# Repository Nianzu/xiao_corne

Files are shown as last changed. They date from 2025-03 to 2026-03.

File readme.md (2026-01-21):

https://docs.espressif.com/projects/rust/book/getting-started/toolchain.html
# Toolchain
```
sudo apt install build-essential
cargo install espup --locked 
espup install
cat $HOME/export-esp.sh >> ~/.bashrc
```
# Tooling
```
cargo install esp-generate --locked
cargo install espflash --locked
cargo install esp-config --features=tui --locked
```

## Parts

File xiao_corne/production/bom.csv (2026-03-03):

Designator | Footprint | Quantity | Value | LCSC Part #
BT1 | PinHeader_1x02_P2.00mm_Vertical | 1 | Battery
C1, C2 | 0805 | 2 | 10uF
C14, C15, C16 | 0805 | 3 | 4.7u
C3 | 0805 | 1 | 1u
C4 | 0805 | 1 | 22u
C7 | 0805 | 1 | 0.1u
C8, C9 | 0805 | 2 | 100nF
D1, D2 | TVS_ESD321DPYR | 2 | ESD321DPYR
D16, D17, D18, D19, D20, D21, D22, D23, D47, D48, D49, D50, D51, D52, D53, D54, D73, D74, D75, D76, D77 | LED_SK6812MINI | 21 | LED_SK6812MINI | C5149201
J1 | GCT_USB4110GFA | 1 | USB4110GFA
J6 | PinHeader_1x04_P2.54mm_Vertical | 1 | Conn_01x04_Socket
R1, R3 | 0805 | 2 | 100k
R10, R7, R8, R9 | 0805 | 4 | 10k
R2, R4 | 0805 | 2 | 22
R5, R6 | 0805 | 2 | 5.1k
S1 | SW_SLW-864574-5A-RA-N-D | 1 | SLW-864574-5A-RA-N-D
SW1, SW11, SW12, SW13, SW14, SW15, SW2, SW21, SW22, SW23, SW24, SW25, SW3, SW31, SW32, SW33, SW34, SW35, SW4, SW41, SW5 | Hotswap_Choc_V1V2 | 21 | SW_Push
SW6 | MJTP1117 | 1 | SW_Push
U1 | D14 | 1 | SN74AHCT125DR
U2 | ESP32-S3-WROOM-1 | 1 | ESP32-S3-WROOM-1
U4 | RGT0016C | 1 | BQ24232RGTR
U5 | QFN-12_MPM3810_MNP | 1 | MPM3810GQB-33-Z

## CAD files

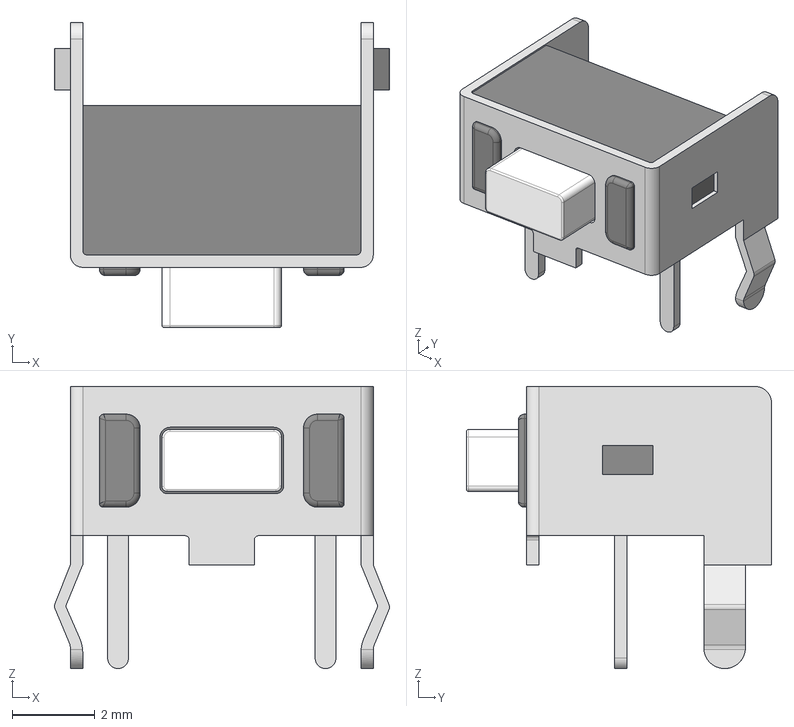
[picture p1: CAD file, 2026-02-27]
xiao_corne/MJTP1117-5483_ASM.step
8.07 x 7.35 x 6.80 mm
MJTP1117-5506_2
MJTP1117-5506_1
MJTP1117-5506_3

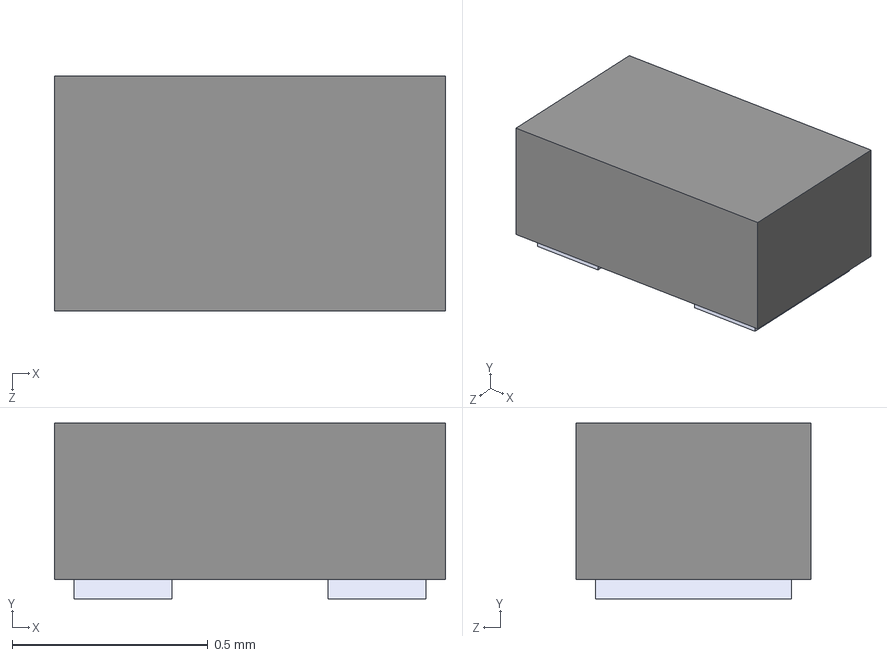
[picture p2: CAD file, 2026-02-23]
xiao_corne/ESD321DPYR/ESD321DPYR.step
1.00 x 0.45 x 0.6 mm

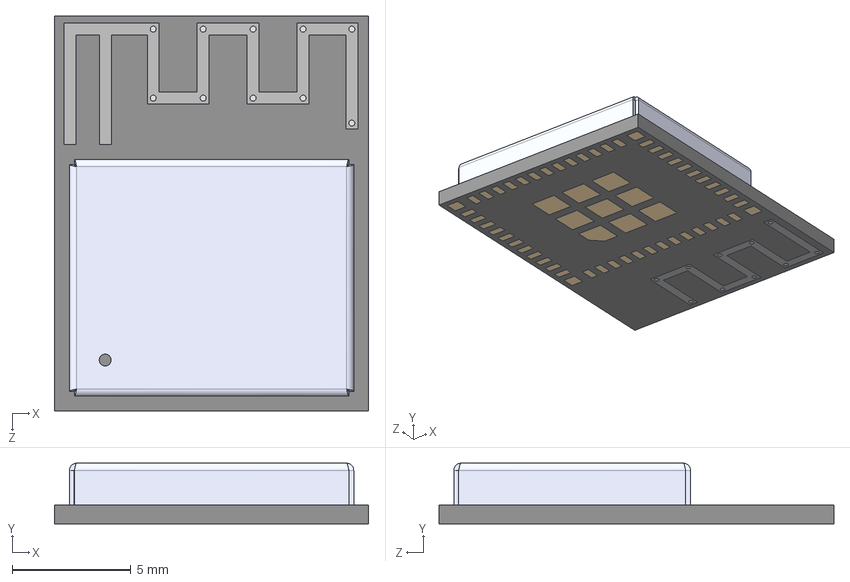
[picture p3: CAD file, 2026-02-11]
xiao_corne/ESP32_C3_MINI_1_N4/ESP32-C3-MINI-1-N4.step
13.2 x 2.55 x 16.6 mm

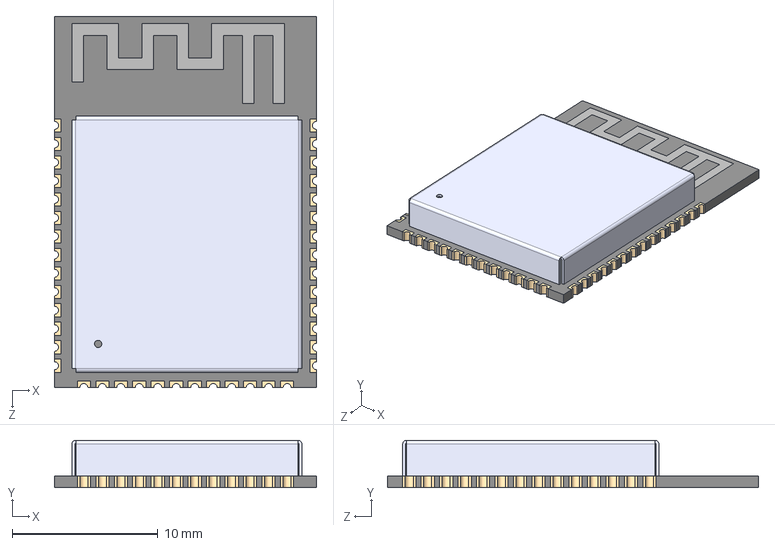
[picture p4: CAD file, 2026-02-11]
xiao_corne/ESP32_S3_WROOM_1_N4/ESP32-S3-WROOM-1-N4.step
18.0 x 3.25 x 25.5 mm

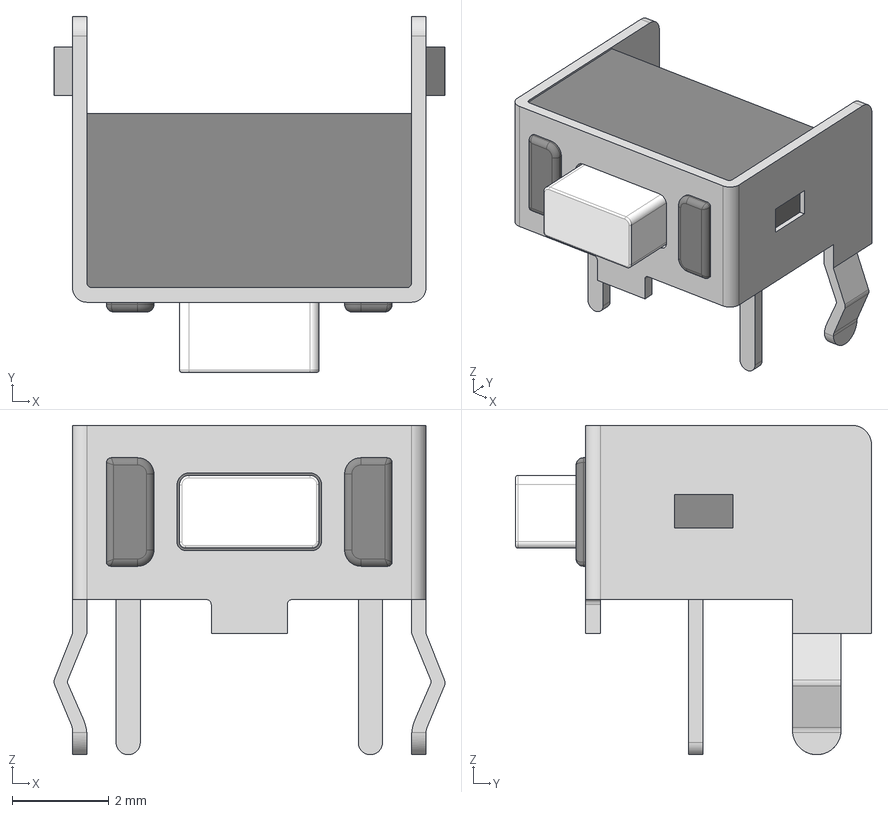
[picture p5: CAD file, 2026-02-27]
xiao_corne/LIB_MJTP1117/MJTP1117/3D/MJTP1117.stp
8.07 x 7.35 x 6.80 mm

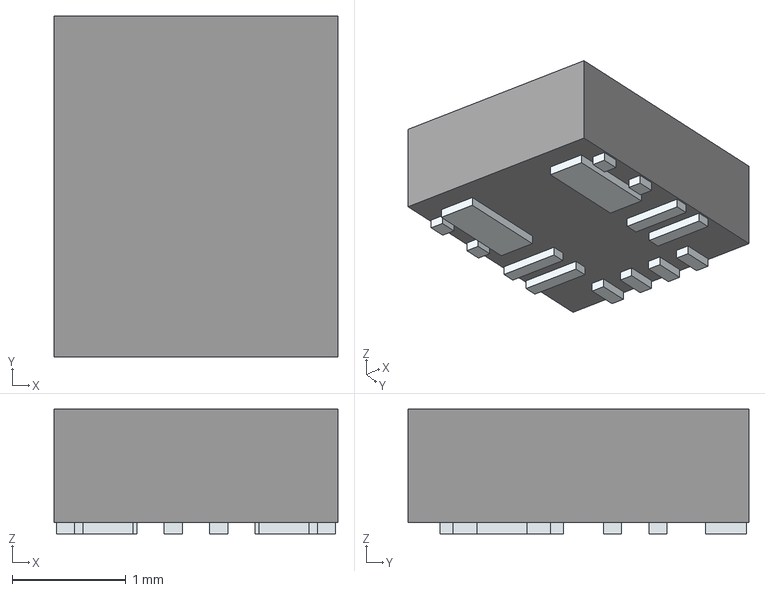
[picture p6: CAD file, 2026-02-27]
xiao_corne/LIB_MPM3810GQB-33-Z/MPM3810GQB-33-Z/3D/MPM3810GQB-33-Z.stp
2.50 x 3.00 x 1.10 mm
Pins

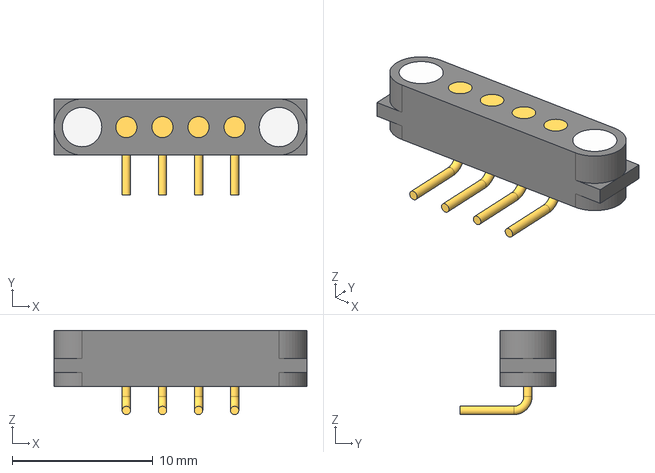
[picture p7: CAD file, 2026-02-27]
xiao_corne/Part Studio 1.step
18.0 x 6.83 x 6.00 mm

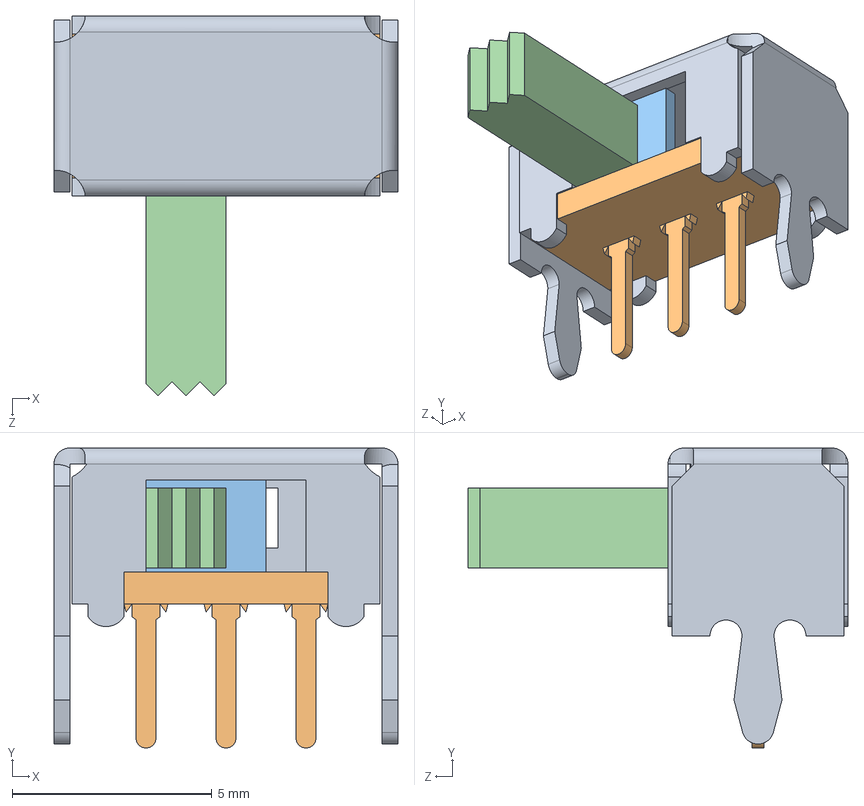
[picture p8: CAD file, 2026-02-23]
xiao_corne/SLW_864574_5A_RA_N_D/SLW-864574-5A-RA-N-D.step
8.60 x 7.50 x 9.50 mm

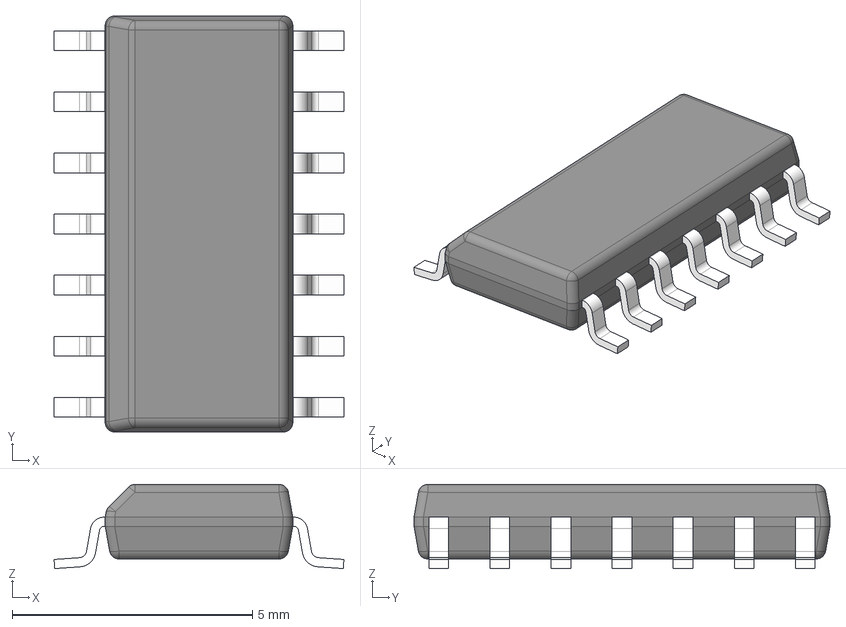
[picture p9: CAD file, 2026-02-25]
xiao_corne/SN74AHCT125DR/SN74AHCT125DR.stp
6.03 x 8.65 x 1.75 mm
BODY-SO
LEAD-SO x 14
PIN1-ID

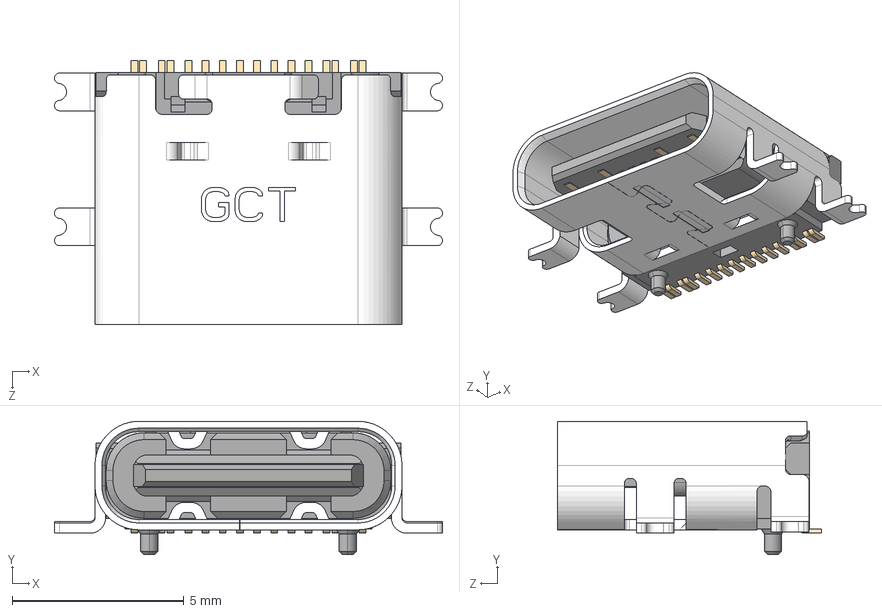
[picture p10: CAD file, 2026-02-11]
xiao_corne/USB4110_GF_A/USB4110GFA.step
11.3 x 3.89 x 7.70 mm

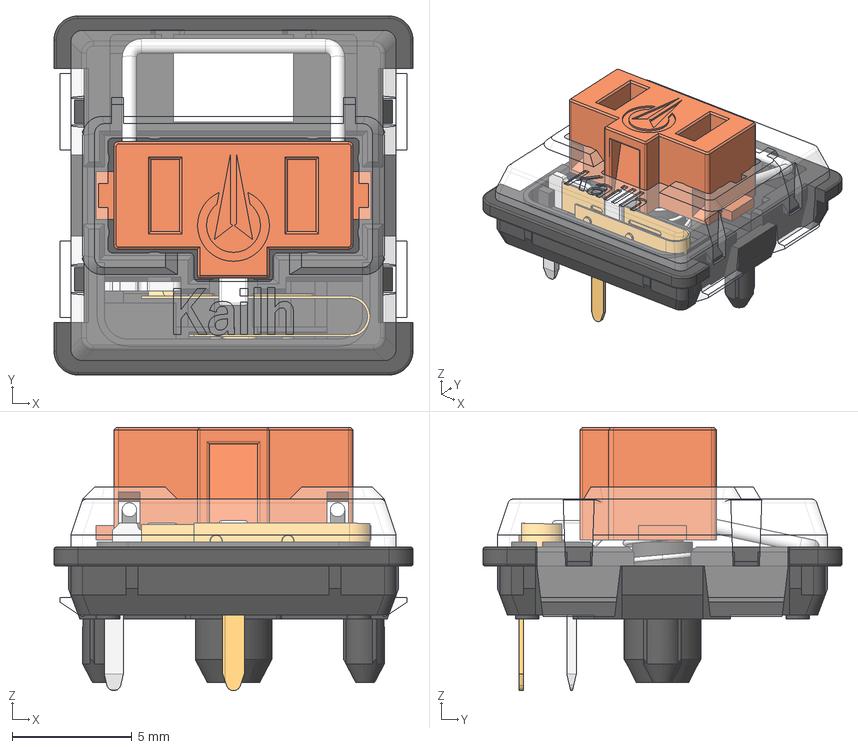
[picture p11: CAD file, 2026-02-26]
xiao_corne/red(1).step
15.0 x 15.0 x 11.0 mm
bottom_stabilizer
contact
pin1
pin2
top_stabilizer
stabilizer
stem_stabilizer
shrunken_spring

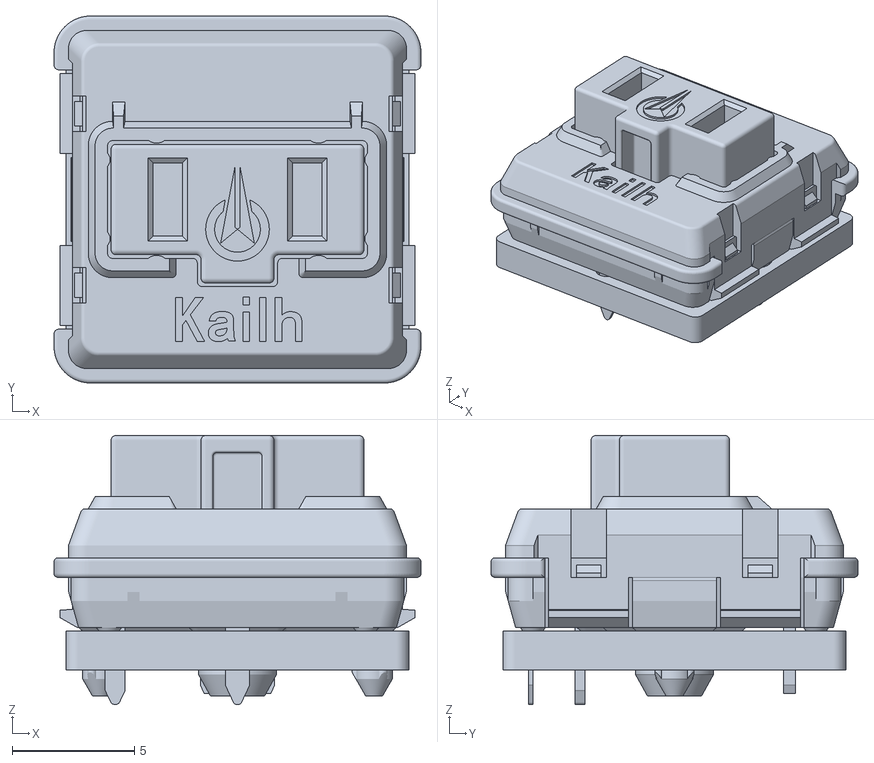
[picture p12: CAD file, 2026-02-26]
xiao_corne/Kailh Choc Low Profile Switch.stl
15.0 x 15.0 x 11.0

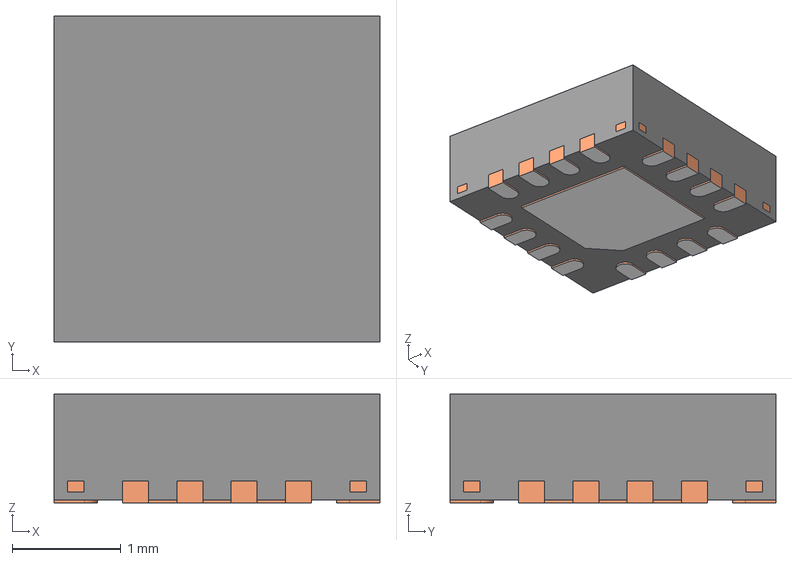
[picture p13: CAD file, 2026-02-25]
xiao_corne/BQ24232RGTR/BQ24232RGTR.stp
3.00 x 3.00 x 1.00 mm
BODY-QFN
FRAME-RGT0016C
PIN1-ID

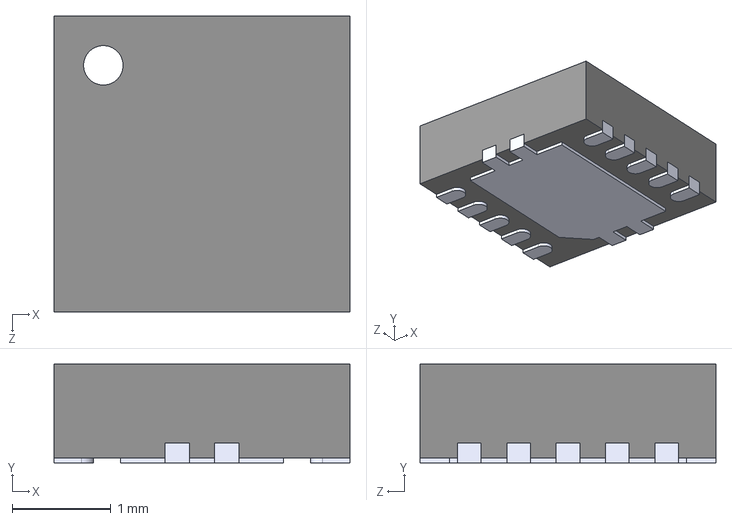
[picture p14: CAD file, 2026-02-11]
xiao_corne/TPS61201DRCT/TPS61201DRCT.step
3.00 x 1.00 x 3.00 mm

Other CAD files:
xiao_corne/LIB_MJTP1117/MJTP1117/Allegro/mjtp1117.psm
xiao_corne/LIB_MJTP1117/MJTP1117/DEHDL/mjtp1117/chips/chips.prt
xiao_corne/LIB_MPM3810GQB-33-Z/MPM3810GQB-33-Z/Allegro/mpm3810gqb33z.psm
xiao_corne/LIB_MPM3810GQB-33-Z/MPM3810GQB-33-Z/DEHDL/mpm3810gqb_33_z/chips/chips.prt

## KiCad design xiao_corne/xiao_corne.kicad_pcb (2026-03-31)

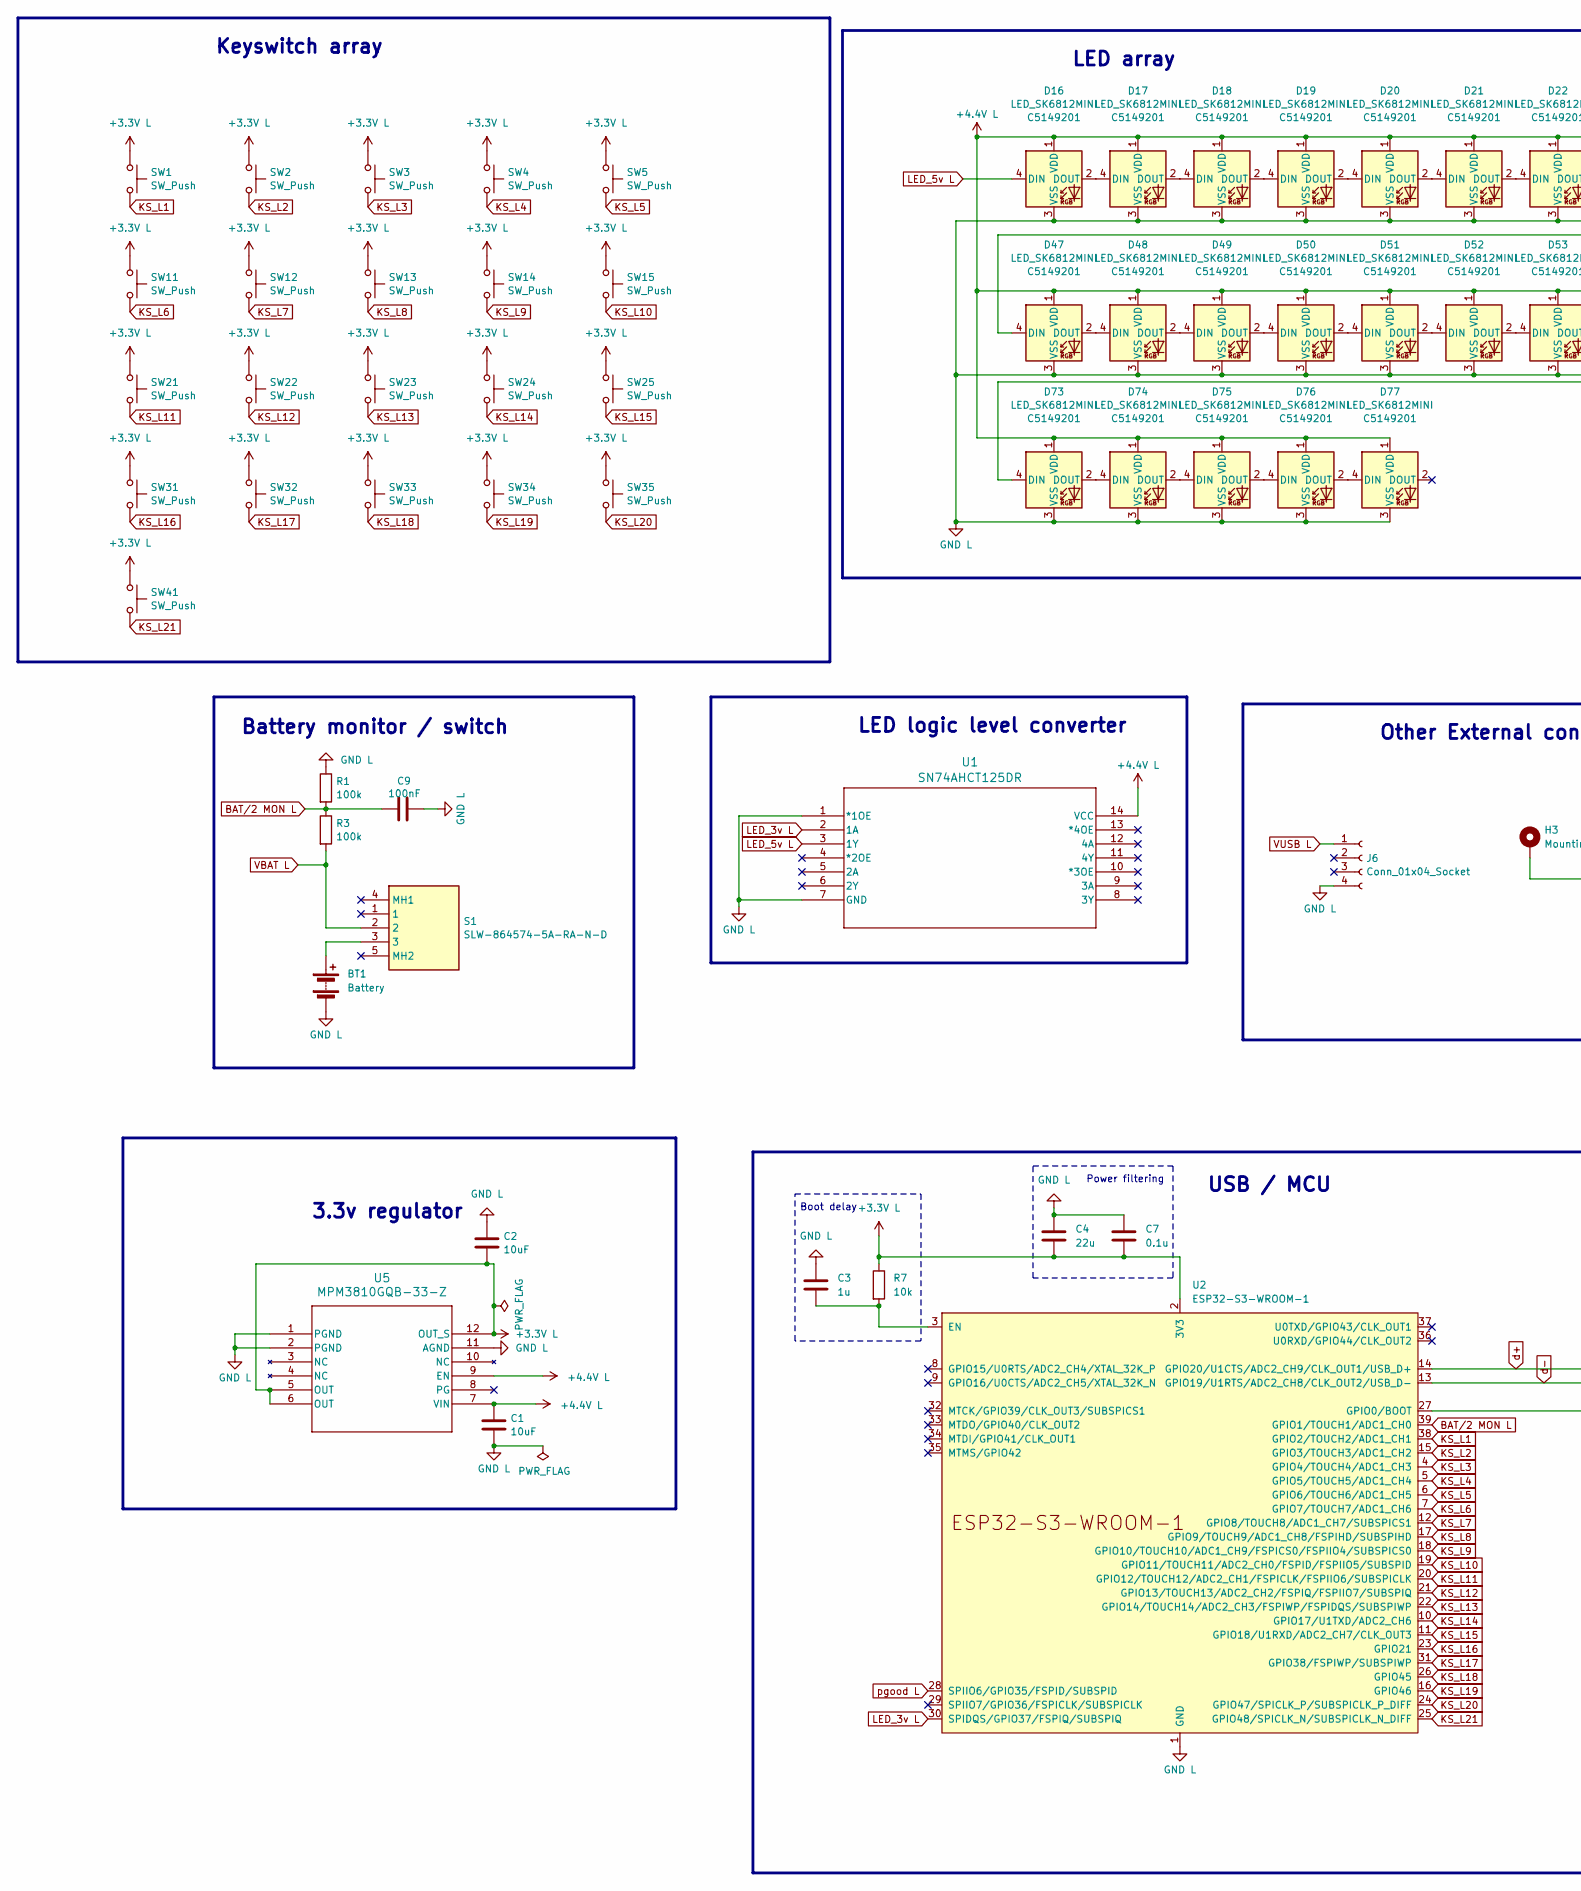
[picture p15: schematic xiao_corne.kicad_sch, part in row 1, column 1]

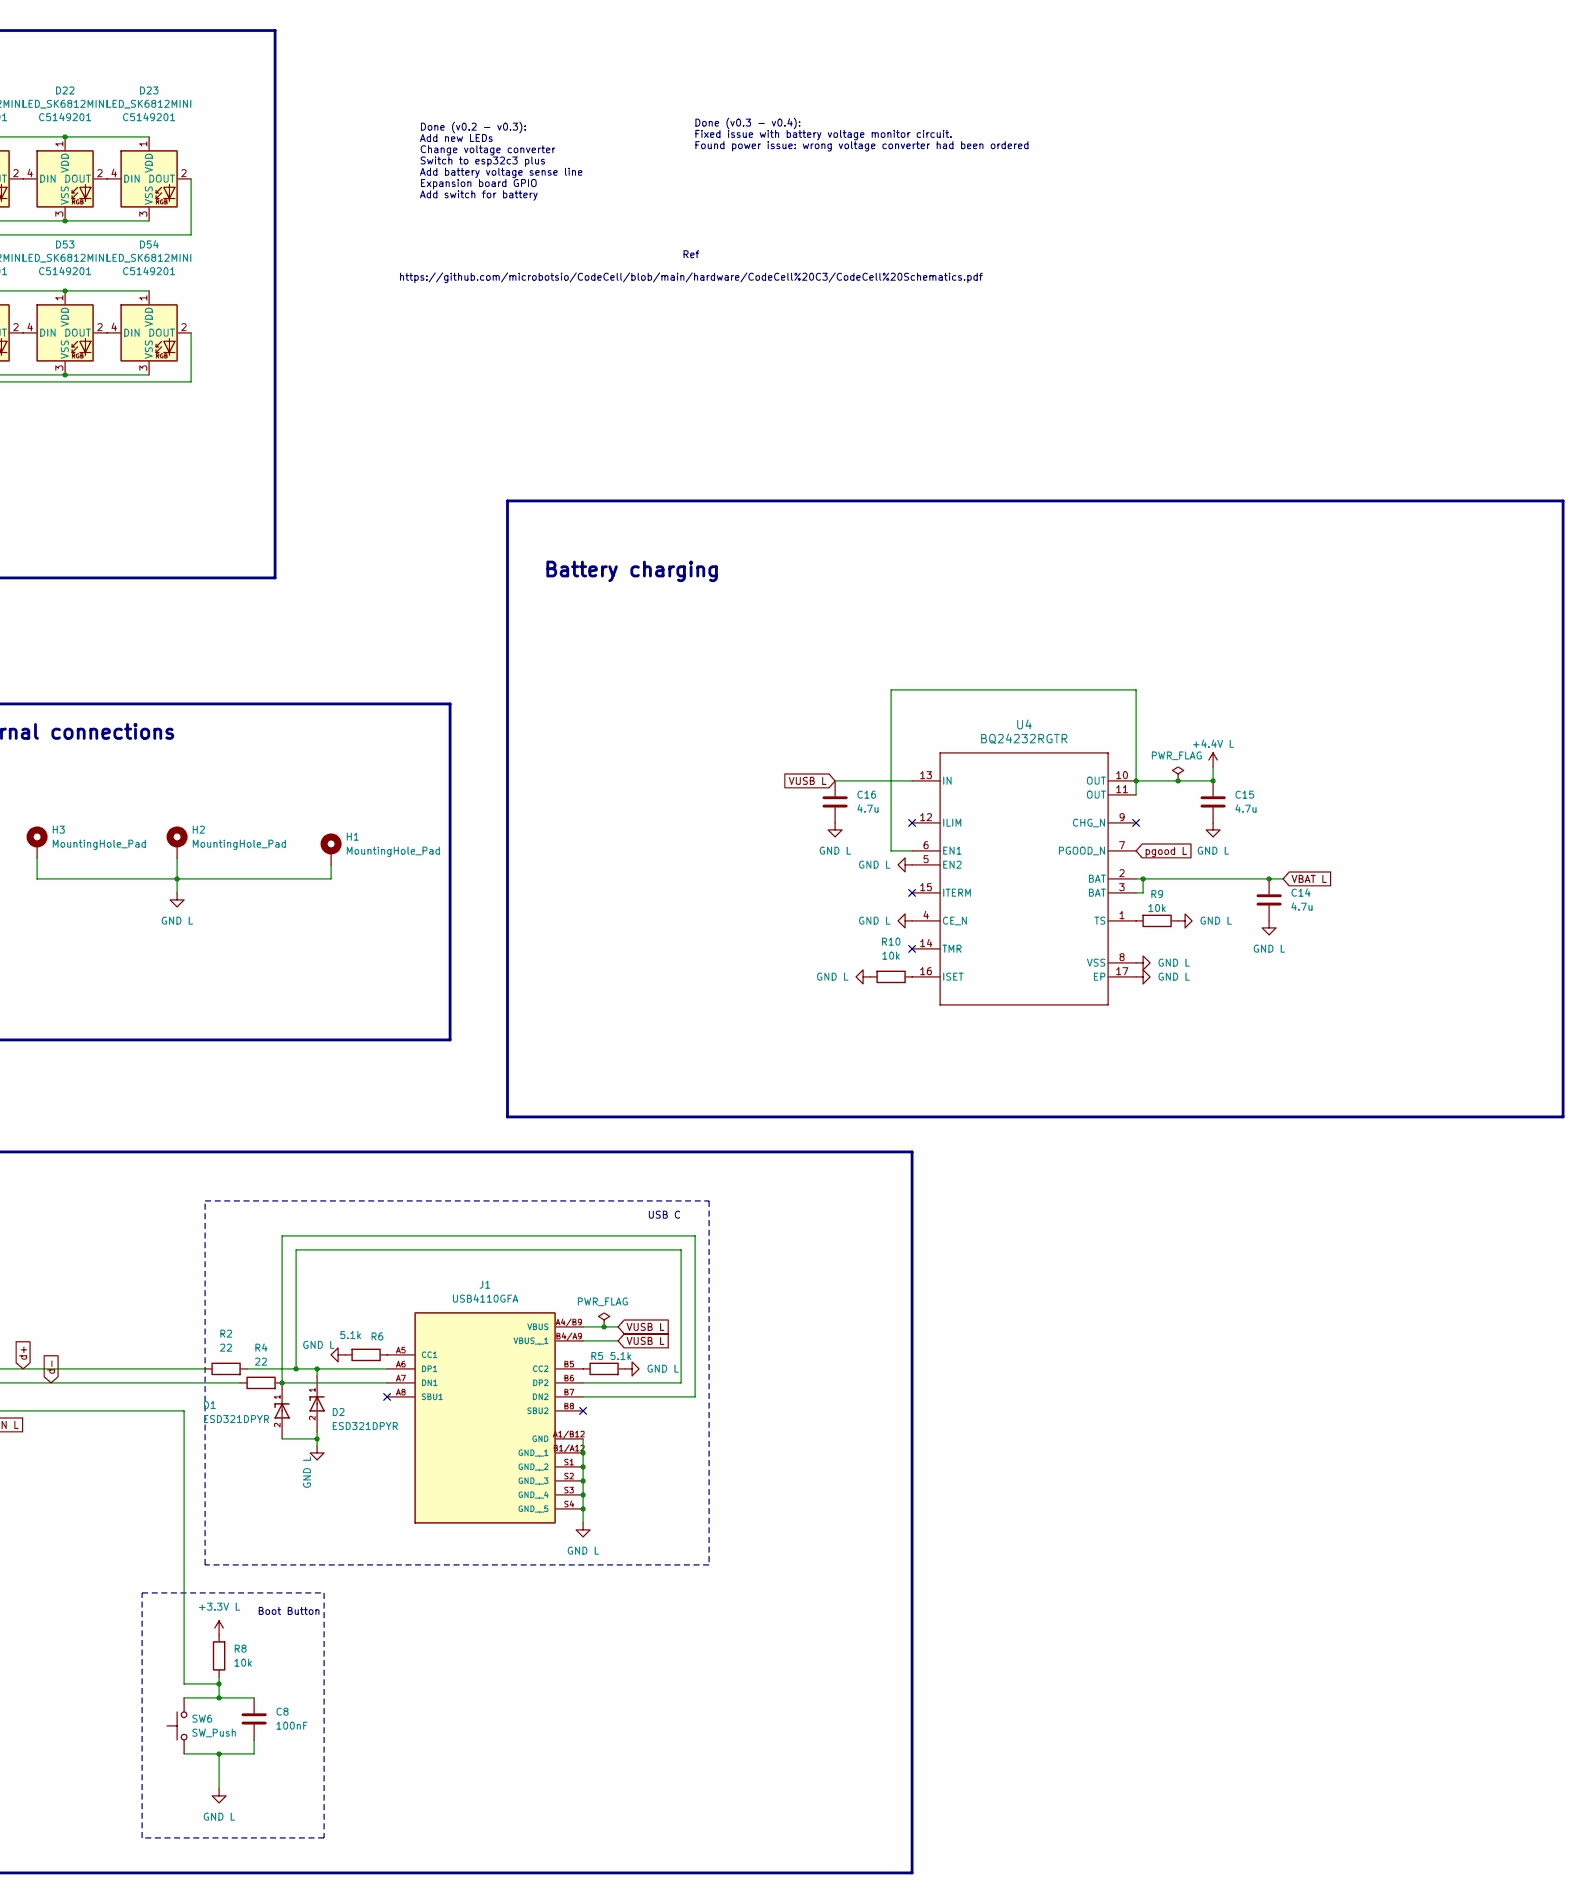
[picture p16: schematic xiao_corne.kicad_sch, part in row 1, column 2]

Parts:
BT1: Battery; PinHeader_1x02_P2.00mm_Vertical
C1, C2: 10uF; C_0805_2012Metric
C3: 1u; C_0805_2012Metric
C4: 22u; C_0805_2012Metric
C7: 0.1u; C_0805_2012Metric
C8, C9: 100nF; C_0805_2012Metric
C14, C15, C16: 4.7u; C_0805_2012Metric
D1, D2: ESD321DPYR; TVS_ESD321DPYR; PARTREV B
D16, D17, D18, D19, D20, D21, D22, D23, D47, D48, D49, D50, D51, D52, D53, D54, D73, D74, D75, D76, D77: LED_SK6812MINI; LCSC C5149201
H1, H2, H3: MountingHole_Pad; MountingHole_2.2mm_M2_ISO14580_Pad_TopBottom
J1: USB4110GFA; GCT_USB4110GFA
J6: Conn_01x04_Socket; PinHeader_1x04_P2.54mm_Vertical
R1, R3: 100k; R_0805_2012Metric
R2, R4: 22; R_0805_2012Metric
R5, R6: 5.1k; R_0805_2012Metric
R7, R8, R9, R10: 10k; R_0805_2012Metric
S1: SLW-864574-5A-RA-N-D; SW_SLW-864574-5A-RA-N-D; Mouser Part Number 179-SLW8645745ARAND
SW1, SW2, SW3, SW4, SW5, SW11, SW12, SW13, SW14, SW15, SW21, SW22, SW23, SW24, SW25, SW31, SW32, SW33, SW34, SW35, SW41: SW_Push; Hotswap_Choc_V1V2
SW6: SW_Push; MJTP1117
U1: SN74AHCT125DR; D14
U2: ESP32-S3-WROOM-1
U4: BQ24232RGTR; RGT0016C
U5: MPM3810GQB-33-Z; QFN-12_MPM3810_MNP

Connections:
+3.3V L: C2.1, C4.2, C7.2, R7.1, R8.2, SW1.1, SW2.1, SW3.1, SW4.1, SW5.1, SW11.1, SW12.1, SW13.1, SW14.1, SW15.1, SW21.1, SW22.1, SW23.1, SW24.1, SW25.1, SW31.1, SW32.1, SW33.1, SW34.1, SW35.1, SW41.1, U2.2 (3V3), U5.5 (OUT), U5.6 (OUT), U5.12 (OUT_S)
+4.4V L: C1.2, C15.1, D16.1 (VDD), D17.1 (VDD), D18.1 (VDD), D19.1 (VDD), D20.1 (VDD), D21.1 (VDD), D22.1 (VDD), D23.1 (VDD), D47.1 (VDD), D48.1 (VDD), D49.1 (VDD), D50.1 (VDD), D51.1 (VDD), D52.1 (VDD), D53.1 (VDD), D54.1 (VDD), D73.1 (VDD), D74.1 (VDD), D75.1 (VDD), D76.1 (VDD), D77.1 (VDD), U1.14 (VCC), U4.6 (EN1), U4.10 (OUT), U4.11 (OUT), U5.7 (VIN), U5.9 (EN)
BAT/2 MON L: C9.2, R1.2, R3.1, U2.39 (GPIO1/TOUCH1/ADC1_CH0)
GND L: BT1.2 (-), C1.1, C2.2, C3.1, C4.1, C7.1, C8.2, C9.1, C14.2, C15.2, C16.2, D1.2, D2.2, D16.3 (VSS), D17.3 (VSS), D18.3 (VSS), D19.3 (VSS), D20.3 (VSS), D21.3 (VSS), D22.3 (VSS), D23.3 (VSS), D47.3 (VSS), D48.3 (VSS), D49.3 (VSS), D50.3 (VSS), D51.3 (VSS), D52.3 (VSS), D53.3 (VSS), D54.3 (VSS), D73.3 (VSS), D74.3 (VSS), D75.3 (VSS), D76.3 (VSS), D77.3 (VSS), H1.1 (1_1), H2.1 (1_1), H3.1 (1_1), J1.A1/B12 (GND), J1.B1/A12 (GND__1), J1.S1 (GND__2), J1.S2 (GND__3), J1.S3 (GND__4), J1.S4 (GND__5), J6.4, R1.1, R5.2, R6.2, R9.1, R10.2, SW6.1, U1.1 (*1OE), U1.7 (GND), U2.1 (GND), U2.40 (GND), U2.41 (GND), U4.4 (CE_N), U4.5 (EN2), U4.8 (VSS), U4.17 (EP), U5.1 (PGND), U5.2 (PGND), U5.11 (AGND)
KS_L1: SW1.2, U2.38 (GPIO2/TOUCH2/ADC1_CH1)
KS_L2: SW2.2, U2.15 (GPIO3/TOUCH3/ADC1_CH2)
KS_L3: SW3.2, U2.4 (GPIO4/TOUCH4/ADC1_CH3)
KS_L4: SW4.2, U2.5 (GPIO5/TOUCH5/ADC1_CH4)
KS_L5: SW5.2, U2.6 (GPIO6/TOUCH6/ADC1_CH5)
KS_L6: SW11.2, U2.7 (GPIO7/TOUCH7/ADC1_CH6)
KS_L7: SW12.2, U2.12 (GPIO8/TOUCH8/ADC1_CH7/SUBSPICS1)
KS_L8: SW13.2, U2.17 (GPIO9/TOUCH9/ADC1_CH8/FSPIHD/SUBSPIHD)
KS_L9: SW14.2, U2.18 (GPIO10/TOUCH10/ADC1_CH9/FSPICS0/FSPIIO4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)
KS_L10: SW15.2, U2.19 (GPIO11/TOUCH11/ADC2_CH0/FSPID/FSPIIO5/S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)
KS_L11: SW21.2, U2.20 (GPIO12/TOUCH12/ADC2_CH1/FSPICLK/FSPIIO6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)
KS_L12: SW22.2, U2.21 (GPIO13/TOUCH13/ADC2_CH2/FSPIQ/FSPIIO7/S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)
KS_L13: SW23.2, U2.22 (GPIO14/TOUCH14/ADC2_CH3/FSPIWP/FSPIDQS/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)
KS_L14: SW24.2, U2.10 (GPIO17/U1TXD/ADC2_CH6)
KS_L15: SW25.2, U2.11 (GPIO18/U1RXD/ADC2_CH7/CLK_OUT3)
KS_L16: SW31.2, U2.23 (GPIO21)
KS_L17: SW32.2, U2.31 (GPIO38/FSPIWP/SUBSPIWP)
KS_L18: SW33.2, U2.26 (GPIO45)
KS_L19: SW34.2, U2.16 (GPIO46)
KS_L20: SW35.2, U2.24 (GPIO47/SPICLK_P/SUBSPICLK_P_DIFF)
KS_L21: SW41.2, U2.25 (GPIO48/SPICLK_N/SUBSPICLK_N_DIFF)
LED_3v L: U1.2 (1A), U2.30 (SPIDQS/GPIO37/FSPIQ/SUBSPIQ)
LED_5v L: D16.4 (DIN), U1.3 (1Y)
unnamed: BT1.1 (+), S1.3
unnamed: D16.2 (DOUT), D17.4 (DIN)
unnamed: D17.2 (DOUT), D18.4 (DIN)
unnamed: D18.2 (DOUT), D19.4 (DIN)
unnamed: D19.2 (DOUT), D20.4 (DIN)
unnamed: D20.2 (DOUT), D21.4 (DIN)
unnamed: D21.2 (DOUT), D22.4 (DIN)
unnamed: D22.2 (DOUT), D23.4 (DIN)
unnamed: D23.2 (DOUT), D47.4 (DIN)
unnamed: D47.2 (DOUT), D48.4 (DIN)
unnamed: D48.2 (DOUT), D49.4 (DIN)
unnamed: D49.2 (DOUT), D50.4 (DIN)
unnamed: D50.2 (DOUT), D51.4 (DIN)
unnamed: D51.2 (DOUT), D52.4 (DIN)
unnamed: D52.2 (DOUT), D53.4 (DIN)
unnamed: D53.2 (DOUT), D54.4 (DIN)
unnamed: D54.2 (DOUT), D73.4 (DIN)
unnamed: D73.2 (DOUT), D74.4 (DIN)
unnamed: D74.2 (DOUT), D75.4 (DIN)
unnamed: D75.2 (DOUT), D76.4 (DIN)
unnamed: D76.2 (DOUT), D77.4 (DIN)
unnamed: J1.A5 (CC1), R6.1
unnamed: J1.B5 (CC2), R5.1
unnamed: D1.1, J1.A7 (DN1), J1.B7 (DN2), R4.2
unnamed: D2.1, J1.A6 (DP1), J1.B6 (DP2), R2.2
unnamed: C3.2, R7.2, U2.3 (EN)
unnamed: C8.1, R8.1, SW6.2, U2.27 (GPIO0/BOOT)
unnamed: R10.1, U4.16 (ISET)
unnamed: R9.2, U4.1 (TS)
VBAT L: C14.1, R3.2, S1.2, U4.2 (BAT), U4.3 (BAT)
VUSB L: C16.1, J1.A4/B9 (VBUS), J1.B4/A9 (VBUS__1), J6.1, U4.13 (IN)
d+: R2.1, U2.14 (GPIO20/U1CTS/ADC2_CH9/CLK_OUT1/USB_D+)
d-: R4.1, U2.13 (GPIO19/U1RTS/ADC2_CH8/CLK_OUT2/USB_D-)
pgood L: U2.28 (SPIIO6/GPIO35/FSPID/SUBSPID), U4.7 (PGOOD_N)

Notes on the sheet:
USB / MCU
Battery charging
USB C
Boot Button
Battery monitor / switch
Keyswitch array
Done (v0.2 - v0.3): Add new LEDs Change voltage converter Switch to esp32c3 plus Add battery voltage sense line Expansion board GPIO Add switch for battery
Boot delay
LED logic level converter
LED array
3.3v regulator
Other External connections
Power filtering
Ref https://github.com/microbotsio/CodeCell/blob/main/hardware/CodeCell%20C3/CodeCell%20Schematics.pdf
Done (v0.3 - v0.4): Fixed issue with battery voltage monitor circuit. Found power issue: wrong voltage converter had been ordered

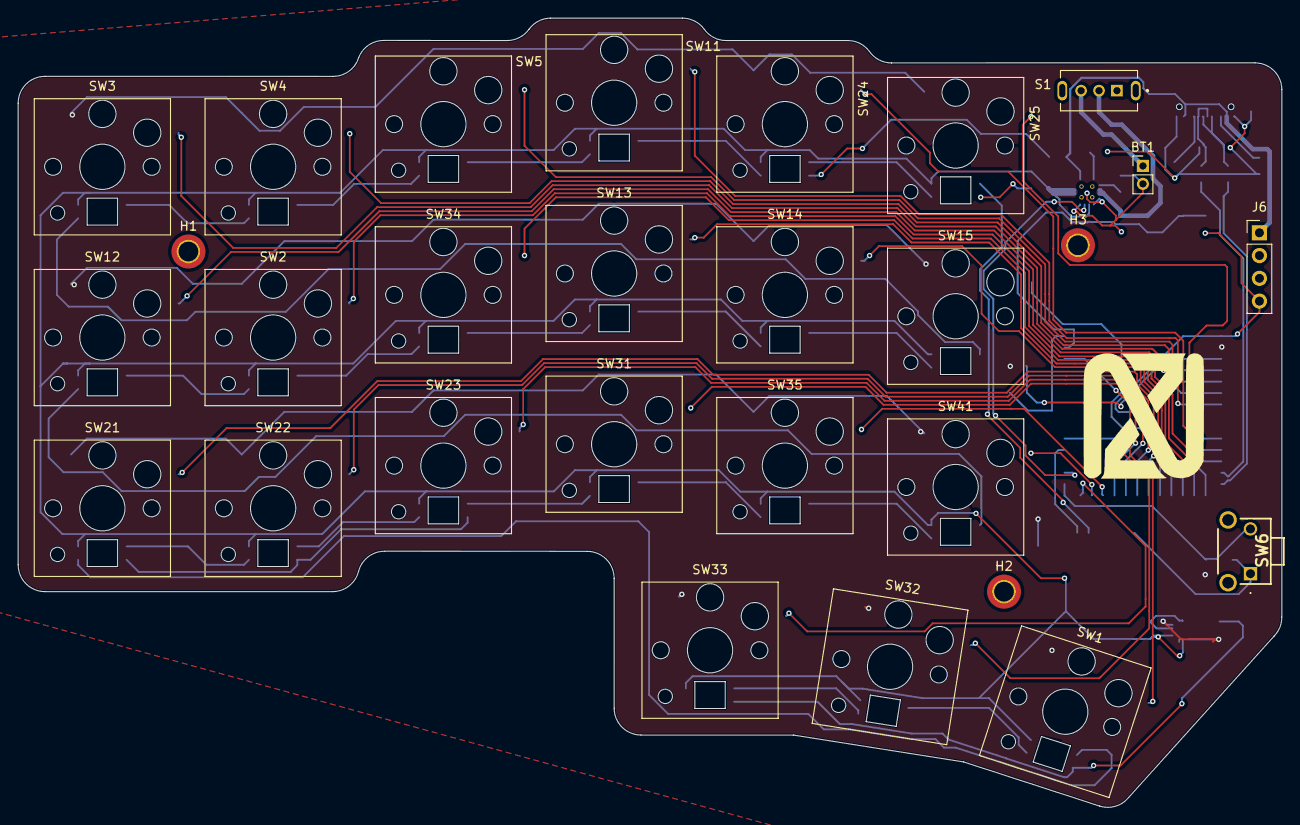
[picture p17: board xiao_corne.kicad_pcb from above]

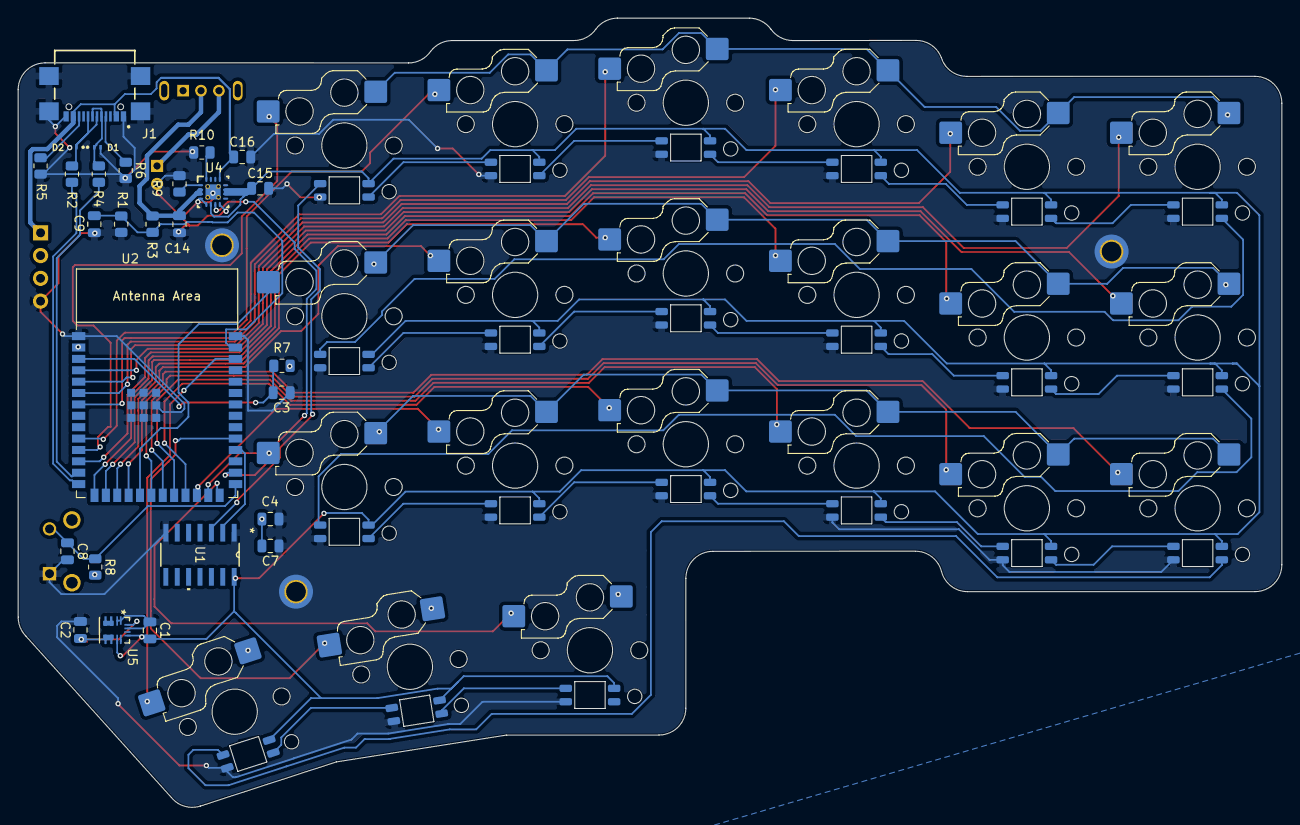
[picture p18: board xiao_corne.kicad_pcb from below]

Board: 2 copper layers, 141.0 x 88.1 mm, 76 parts (48 on the bottom side), 61 nets.

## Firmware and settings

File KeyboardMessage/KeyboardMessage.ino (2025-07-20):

#ifndef ARDUINO_USB_MODE
#error This ESP32 SoC has no Native USB interface
#elif ARDUINO_USB_MODE == 1
#error This sketch should be used when USB is in OTG mode
#else

#include "USB.h"

#include "ESP32_NOW.h"
#include "WiFi.h"
// For the MAC2STR and MACSTR macros
#include <esp_mac.h>
#include <vector>

#define IS_LEFT

#ifdef IS_LEFT
#include "layout_left.h"
#else
#include "layout_right.h"
#endif
#include "types.h"

#define ESPNOW_WIFI_CHANNEL 6
#define NUM_ROWS 5
#define NUM_COLS 5
#define PAIRING_BROADCAST_DELAY 1000


USBHIDKeyboard Keyboard;

int active_layer = 0;
bool LEDs_updated = false;


int led_map[4][6] = {
  { 0, 1, 2, 3, 4, 5 },
  { 15, 14, 13, 10, 9, 6 },
  { 16, 17, 12, 11, 8, 7 },
  { 20, 19, 18, -1, -1, -1 },
};


class ESP_NOW_Broadcast_Peer : public ESP_NOW_Peer {
public:
  // Constructor of the class using the broadcast address
  ESP_NOW_Broadcast_Peer(uint8_t channel, wifi_interface_t iface, const uint8_t *lmk)
    : ESP_NOW_Peer(ESP_NOW.BROADCAST_ADDR, channel, iface, lmk) {}

  // Destructor of the class
  ~ESP_NOW_Broadcast_Peer() {
    remove();
  }

  // Function to properly initialize the ESP-NOW and register the broadcast peer
  bool begin() {
    if (!ESP_NOW.begin() || !add()) {
      log_e("Failed to initialize ESP-NOW or register the broadcast peer");
      return false;
    }
    return true;
  }

  // Function to send a message to all devices within the network
  bool send_message(const uint8_t *data, size_t len) {
    if (!send(data, len)) {
      log_e("Failed to broadcast message");
      return false;
    }
    return true;
  }
};

class ESP_NOW_Peer_Class : public ESP_NOW_Peer {
public:
  // Constructor of the class
  ESP_NOW_Peer_Class(const uint8_t *mac_addr, uint8_t channel, wifi_interface_t iface, const uint8_t *lmk)
    : ESP_NOW_Peer(mac_addr, channel, iface, lmk) {}

  // Destructor of the class
  ~ESP_NOW_Peer_Class() {}

  // Function to register the master peer
  bool add_peer() {
    if (!add()) {
      log_e("Failed to register the broadcast peer");
      return false;
    }
    return true;
  }

  // Function to print the received messages from the master
  void onReceive(const uint8_t *data, size_t len, bool broadcast) {

    // Make a copy of the data to ensure null-termination
    char message[33];  // 32 + 1 for null terminator
    len = len > 32 ? 32 : len;
    memcpy(message, data, len);
    message[len] = '\0';

    // Parse message: format is 'P<num>' or 'R<num>' or 'L<num>'
    if (message[0] == 'P' || message[0] == 'R' || message[0] == 'L') {
      int keycode = atoi(&message[1]);  // Convert from string to int
      if (message[0] == 'P') {
        Keyboard.press(keycode);
      } else if (message[0] == 'R') {
        Keyboard.release(keycode);

      } else if (message[0] == 'L') {
        active_layer = keycode;
        Keyboard.releaseAll();

        pixels.clear();
        for (int i = 0; i < 4; i++) {
          for (int j = 0; j < 6; j++) {

            if (led_map[i][j] != -1) {
              pixels.setPixelColor(led_map[i][j], led_layer_map[active_layer][i][j]);
            }
          }
        }
        LEDs_updated = true;
      }
    }
  }

  // Function to send a message to a device
  bool send_message(const uint8_t *data, size_t len) {
    if (!send(data, len)) {
      log_e("Failed to broadcast message");
      return false;
    }
    return true;
  }
};


int last_state[5][5] = {
  { 0, 0, 0, 0, 0 },
  { 0, 0, 0, 0, 0 },
  { 0, 0, 0, 0, 0 },
  { 0, 0, 0, 0, 0 },
  { 0, 0, 0, 0, 0 },
};

// GPIO pins used for the matrix rows and columns
int gpio_cols[NUM_COLS] = { 6, 43, 44, 7, 8 };
int gpio_rows[NUM_ROWS] = { 1, 2, 3, 4, 5 };

// 0: Waiting
// 1: Sending broadcasts
// 2: Paired
int pairing_state = 0;

unsigned long last_broadcast_ms = 0;

ESP_NOW_Broadcast_Peer broadcast_peer(ESPNOW_WIFI_CHANNEL, WIFI_IF_STA, NULL);
std::vector<ESP_NOW_Peer_Class> paired_devices;

void handle_keycode(int keycode, bool down) {
  if (down) {
    Keyboard.press(keycode);
  } else {
    Keyboard.release(keycode);
  }
  if (pairing_state == 2) {
    char data[32];
    snprintf(data, sizeof(data), "%c%d", down ? 'P' : 'R', keycode);
    paired_devices.back().send_message((uint8_t *)data, sizeof(data));
  }
}

void handle_layer(int layer) {
  active_layer = layer;
  Keyboard.releaseAll();
  char data[32];
  if (pairing_state == 2) {
    snprintf(data, sizeof(data), "L%d", active_layer);
    paired_devices.back().send_message((uint8_t *)data, sizeof(data));
  }
  pixels.clear();
  for (int i = 0; i < 4; i++) {
    for (int j = 0; j < 6; j++) {
      if (led_map[i][j] != -1) {
        pixels.setPixelColor(led_map[i][j], led_layer_map[active_layer][i][j]);
      }
    }
  }
  LEDs_updated = true;
}

void handle_macro(int macro) {
  // future work
}

void perform_action(Key key, bool down) {
  Action action = action_map[active_layer][key.y][key.x];

  switch (action.type) {
    case ACTION_NONE:
      break;
    case ACTION_KEYCODE:
      handle_keycode(action.value, down);
      break;
    case ACTION_LAYER:
      if (down) handle_layer(action.value);
      break;
    case ACTION_MACRO:
      if (down) handle_macro(action.value);
      break;
  }
  if (down && pairing_state != 2) {
    if (key.y == 1 && key.x == 1) {
      pairing_state = 1;
    }
  }

  pixels.setPixelColor(led_map[key.y][key.x], down ? red : led_layer_map[active_layer][key.y][key.x]);
  LEDs_updated = true;
}

void register_new_peer(const esp_now_recv_info_t *info, const uint8_t *data, int len, void *arg) {
  if (paired_devices.size() == 0) {

    ESP_NOW_Peer_Class new_peer(info->src_addr, ESPNOW_WIFI_CHANNEL, WIFI_IF_STA, NULL);

    paired_devices.push_back(new_peer);
    if (!paired_devices.back().add_peer()) {
      log_v("Failed to register the new master");
      return;
    }
    char data[32];
    snprintf(data, sizeof(data), "Unicast reply for pairing");
    broadcast_peer.send_message((uint8_t *)data, sizeof(data));
  } else {
    // The slave will only receive broadcast messages
    log_v("Received a unicast message from " MACSTR, MAC2STR(info->src_addr));
    log_v("Igorning the message");
  }
}

void setup() {
  // Initialize control over the Keyboard
  Keyboard.begin();
  USB.begin();

  // Startup the neopixel driver
  pixels.begin();
  pixels.clear();
  pixels.show();

  // Set the gpio direction
  for (int c = 0; c < NUM_COLS; c++) {
    pinMode(gpio_cols[c], OUTPUT);
    digitalWrite(gpio_cols[c], LOW);
  }
  for (int r = 0; r < NUM_ROWS; r++) {
    pinMode(gpio_rows[r], INPUT_PULLDOWN);
  }

  // Initialize the Wi-Fi module
  WiFi.mode(WIFI_STA);
  WiFi.setChannel(ESPNOW_WIFI_CHANNEL);
  while (!WiFi.STA.started()) {
    delay(100);
  }

  // Register the broadcast peer
  if (!broadcast_peer.begin()) {
    delay(5000);
    ESP.restart();
  }

  // Register the new peer callback
  ESP_NOW.onNewPeer(register_new_peer, NULL);
}

void loop() {
  for (int c = 0; c < NUM_COLS; c++) {
    digitalWrite(gpio_cols[c], HIGH);
    delayMicroseconds(5);  // Slight delay for signal settling
    for (int r = 0; r < NUM_ROWS; r++) {
      int current_state = digitalRead(gpio_rows[r]);
      delay(1);

      if (last_state[r][c] != current_state) {
        last_state[r][c] = current_state;

        perform_action(key_map[r][c], current_state);
      }
    }
    digitalWrite(gpio_cols[c], LOW);
  }

  if (pairing_state == 0) {
    pixels.setPixelColor(led_map[1][1], teal);
    LEDs_updated = true;
  } else if (pairing_state == 1) {
    if (last_broadcast_ms + PAIRING_BROADCAST_DELAY < millis()) {
      last_broadcast_ms = millis();
      char data[32];
      snprintf(data, sizeof(data), "Broadcast for pairing");
      broadcast_peer.send_message((uint8_t *)data, sizeof(data));
    }

    pixels.setPixelColor(led_map[1][1], white);
    LEDs_updated = true;
  }
  if (pairing_state != 2) {
    if (paired_devices.size() > 0) {
      pairing_state = 2;
      pixels.clear();
      LEDs_updated = true;
    }
  }
  if (LEDs_updated) {
    pixels.show();
    LEDs_updated = false;
  }
}
#endif /* ARDUINO_USB_MODE */

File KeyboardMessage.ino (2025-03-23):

/*
  Keyboard Message test

  For the Arduino Leonardo and Micro.

  Sends a text string when a button is pressed.

  The circuit:
  - pushbutton attached from pin 0 to ground
  - 10 kilohm resistor attached from pin 0 to +5V

  created 24 Oct 2011
  modified 27 Mar 2012
  by Tom Igoe
  modified 11 Nov 2013
  by Scott Fitzgerald

  This example code is in the public domain.

  http://www.arduino.cc/en/Tutorial/KeyboardMessage
*/
#ifndef ARDUINO_USB_MODE
#error This ESP32 SoC has no Native USB interface
#elif ARDUINO_USB_MODE == 1
#warning This sketch should be used when USB is in OTG mode
void setup() {}
void loop() {}
#else

#include "USB.h"
#include "USBHIDKeyboard.h"
USBHIDKeyboard Keyboard;

int last_state[5][5] = {
  {0, 0, 0, 0, 0},
  {0, 0, 0, 0, 0},
  {0, 0, 0, 0, 0},
  {0, 0, 0, 0, 0},
  {0, 0, 0, 0, 0},
};

int keymap[5][5] = {
  {1, 2, 3, 4, 5},
  {6, 7, 8, 9, 10},
  {11, 12, 13, 14, 15},
  {16, 17, 18, 19, 20},
  {21, 22, 23, 24, 25},
};

int cols[5] = {6, 43, 44, 7, 8};
int rows[5] = {1, 2, 3, 4, 5};

void setup() {
  Serial1.end();
  for (int r = 0; r < sizeof rows / sizeof rows[0]; r++) {
    pinMode(rows[r], INPUT_PULLDOWN);
  }
  for (int c = 0; c < sizeof cols / sizeof cols[0]; c++) {
    pinMode(cols[c], OUTPUT);
    digitalWrite(cols[c], LOW);
  }

  // initialize control over the keyboard:
  Keyboard.begin();
  USB.begin();
}

void loop() {
  for (int c = 0; c < sizeof cols / sizeof cols[0]; c++) {
    digitalWrite(cols[c], HIGH);
    for (int r = 0; r < sizeof rows / sizeof rows[0]; r++) {
      int current_state = digitalRead(rows[r]);
      delay(1);

      if (last_state[r][c] != current_state) {
        last_state[r][c] = current_state;
        if (current_state) {
          Keyboard.println(keymap[r][c]);
        }
      }

    }
    digitalWrite(cols[c], LOW);
  }
}
#endif /* ARDUINO_USB_MODE */

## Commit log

2025-03-23 first production test
    [bom.csv, designators.csv, positions.csv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]
2025-03-30 Hardware V0.2
    [bom.csv, designators.csv, positions.csv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]
2025-05-08 Left half keyboard basic fully working, minus LEDs
2025-05-08 LEDs working. So many wasted hours, because the adafruit library broke after 1.12.3.........
    [KeyboardMessage.ino]
2025-05-08 Fully working for both left and right sides individualy, with LEDs!
2025-05-08 I wrote this commit message with my now fully functional keyboard. LEDs and all
2025-05-09 Removed serial port, added key release on layer switch
2025-05-15 Set LEDs to batch update.
2025-05-16 Revert "migrate esp code to own file"
    This reverts commit 80cdbd023e9a3cd406f6e0397eed5206af872bd4.
    [KeyboardMessage.ino]
2025-05-16 Fix but with definitions out of order
    [KeyboardMessage.ino]
2025-05-16 LED layer functionality added for left side!
2025-05-16 Added LED map to right side, fixed overwritting issue
    [KeyboardMessage.ino]
2025-07-20 Major work for update to 0.3!
    [xiao_corne.kicad_pcb, xiao_corne.kicad_sch, xiao_corne.step]
2025-07-20 Production files for v0.3
    [bom.csv, designators.csv, positions.csv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]
2025-07-22 Added 3d models for pretty much everything
    [xiao_corne.kicad_pcb]
2025-07-22 increased heat via size to be manufactureable
    [xiao_corne.kicad_pcb]
2025-07-22 Created manufacturing files to reflect change
    [bom.csv, designators.csv, positions.csv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]
2025-11-15 Fixed issue with battery voltage monitor
    [xiao_corne.kicad_pcb, xiao_corne.kicad_sch]
2026-01-19 Found some issues with the PCB, updated layout
    [xiao_corne.kicad_pcb, xiao_corne.kicad_sch]
2026-01-21 Auto-generated rust boilerplate for esp32s3. Printing hello world!
2026-02-11 WIP large upgrade to keyboard design
    [ESP32-C3-MINI-1-N4.step, ESP32-S3-WROOM-1-N4.step, TPS61201DRCT.step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]
2026-02-16 Finished sketch of schematic
    [xiao_corne.kicad_sch]
2026-02-23 starting layout for left side
    [ESD321DPYR.step, SLW-864574-5A-RA-N-D.step, xiao_corne.kicad_pcb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]
2026-02-25 almost done routing left half!
    [BQ24232RGTR.stp, SN74AHCT125DR.stp, xiao_corne.kicad_pcb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]
2026-02-26 ready for review
    [Kailh Choc Low Profile Switch.stl, red(1).step, xiao_corne.kicad_pcb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]
2026-02-27 changed 3.3v regulator to step down from step up converter
    [EDI2CAP.CFG, MJTP1117-5483_ASM.step, MJTP1117.PcbLib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]
2026-03-31 Fixed issue with battery monitor
    [xiao_corne.kicad_pcb, xiao_corne.kicad_sch]
